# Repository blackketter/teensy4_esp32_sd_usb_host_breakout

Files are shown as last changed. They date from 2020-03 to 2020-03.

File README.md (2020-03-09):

# Teensy 4.0 ESP32 / USB Host / MicroSD Breakout Board

A jumbo breakout board with ESP32, USB-A host and microSD connectors to mate with the [Teensy 4 Header Breakout Board](https://github.com/blackketter/teensy4_header_breakout).

Additionally, the board includes a space for RTC Battery Holder and provides another Teensy reset/programming button (since it covers up the one on the Teensy).

It's designed to mount above or below the Teensy 4 and Header Breakout board on a relatively tall header.

Designed in KiCad.

### Notes:

- Status: Version 1.0 board ordered
- [OSHPark]() (https://oshpark.com/projects/xaSKCWHX)
- Download bom/ibom.html and view it with web browser to see bill of materials and placement information.

### Options

* Three jumpers on the back:
  * JP1 - Short to use Teensy 3.3v to power ESP32 (instead of onboard 3.3v regulator)
  * JP3 - Cut left side, bridge right side to disable D27 as USB Power Enable
  * JP2 - Cut to disable D29 as SD card detect

### Connectors
* J1 and J3 connect to the [Teensy 4 Header Breakout Board](https://github.com/blackketter/teensy4_header_breakout) pins via a header
* J5 is optional and provides access to the onboard 3.3v regulator
* J6 & J7 are optional and provide connection to the corresponding pins directly below on Teensy.  These connect the ESP32 SPI to the Teensy SPI port for high-speed goodness.  Should be compatible with the Adafruit Airlift firmware.
* J2 is a USB-A host connector
* J4 is a MicroSD push-pull connector

### Additional features
* Teensy programming button
* Socket for 12mm lithium backup batter for RTC
* RGB and White LEDs connected to ESP32 for additional status

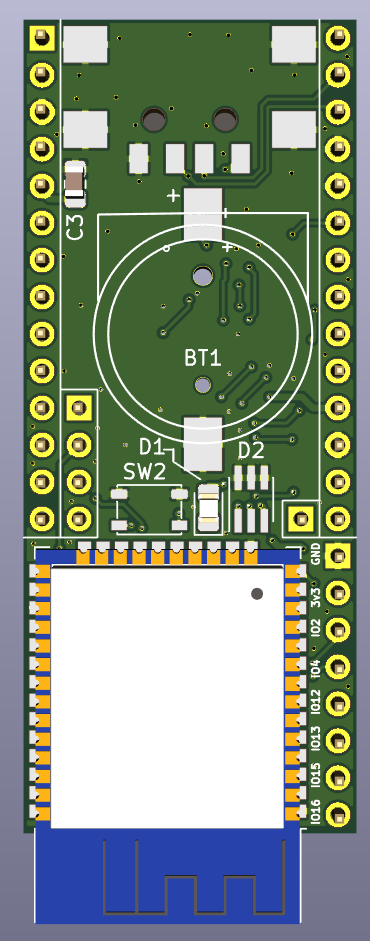
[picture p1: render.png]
breakout render

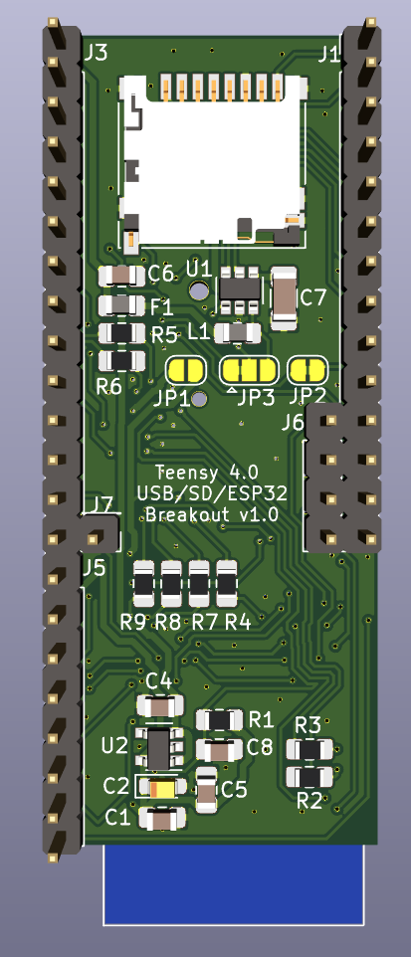
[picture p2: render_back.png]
breakout render_back

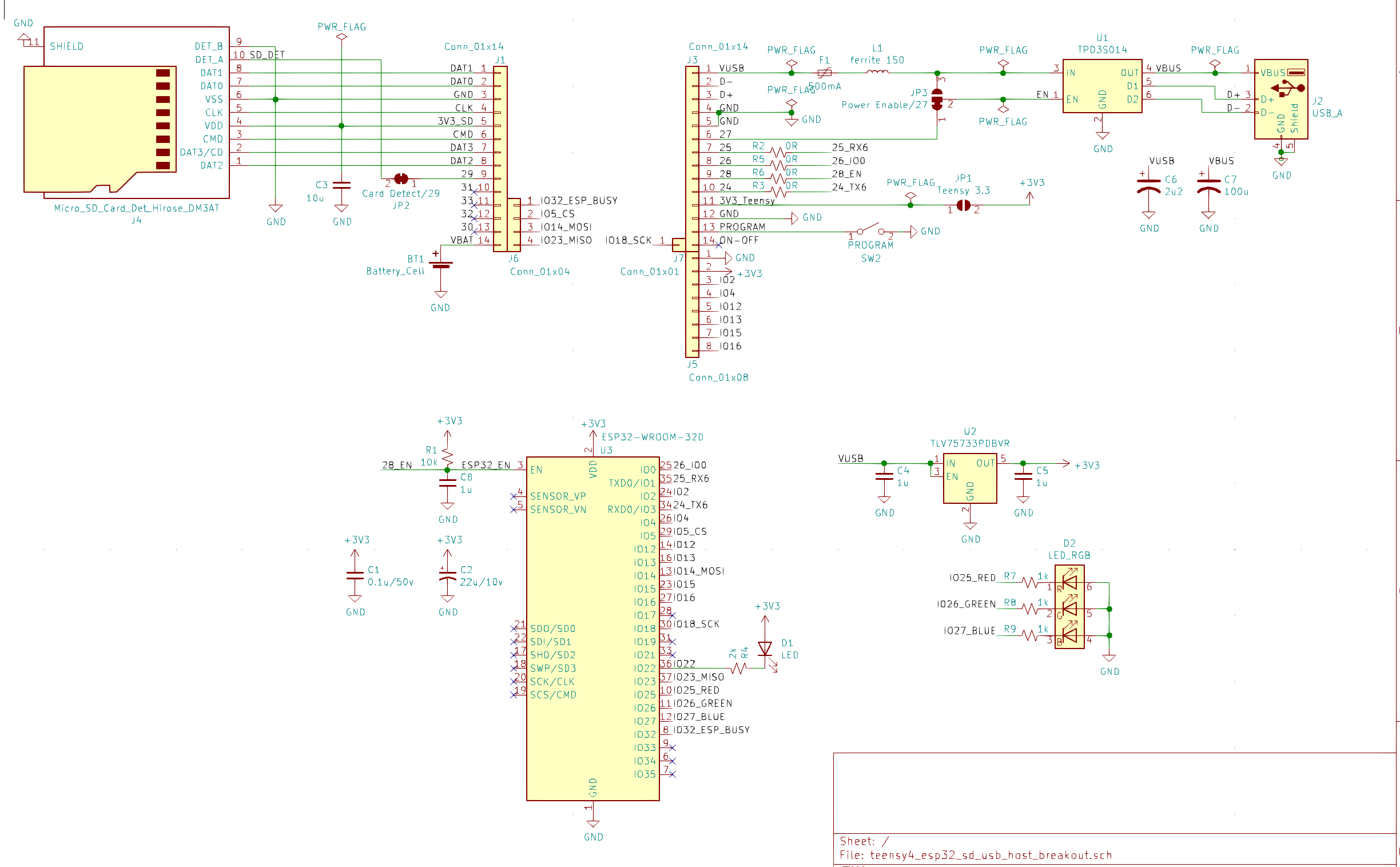
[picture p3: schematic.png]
schematic


**J1 - Left Side Pinout:**

1. Teensy D34 / SD DAT1
2. Teensy D35 / SD DAT0
3. GND
4. Teensy D36 / SD CLK
5. Teensy 3.3v
6. Teensy D37 / SD CMD
7. Teensy D38 / SD DAT3
8. Teensy D39 / SD DAT2
9. Teensy D29 / Card Detect
10. Teensy D31 (unused)
11. Teensy D33 (unused)
12. Teensy D32 (unused)
13. Teensy D30 (unused)
14. Teensy VBAT (battery backup)

**J3 - Right Side Pinout:**

1. Teensy VUSB
2. Teensy USB Host D-
3. Teensy USB Host D+
4. GND
5. GND
6. Teensy D27/USB Power EN
7. Teensy D25/ESP32 IO1 (Serial RX)
8. Teensy D26 / ESP32 IO0 (Boot Mode)
9. Teensy D28 / ESP32 EN (Reset)
10. Teensy D24 / ESP IO3 (Serial TX)
11. Teensy 3.3v
12. GND
13. Teensy Program
14. Teensy On/Off (unused)

**J5 - Optional additional pins**

15. GND
16. 3.3v from regulator on breakout board
17. ESP32 IO2
18. ESP32 IO4
19. ESP32 IO12
20. ESP32 IO13
21. ESP32 IO15
22. ESP32 IO16

**J6 - SPI between ESP32 and Teensy**

1. Teensy D9 / ESP32 IO32 (Busy)
2. Teensy D10 / ESP32 IO5 (CS)
3. Teensy D11 / ESP32 IO14 (MOSI)
4. Teensy D12 / ESP32 IO23 (MISO)

**J7 - SPI between ESP32 and Teensy (cont.)**

1. Teensy D13 / ESP32 IO18 (SCK)

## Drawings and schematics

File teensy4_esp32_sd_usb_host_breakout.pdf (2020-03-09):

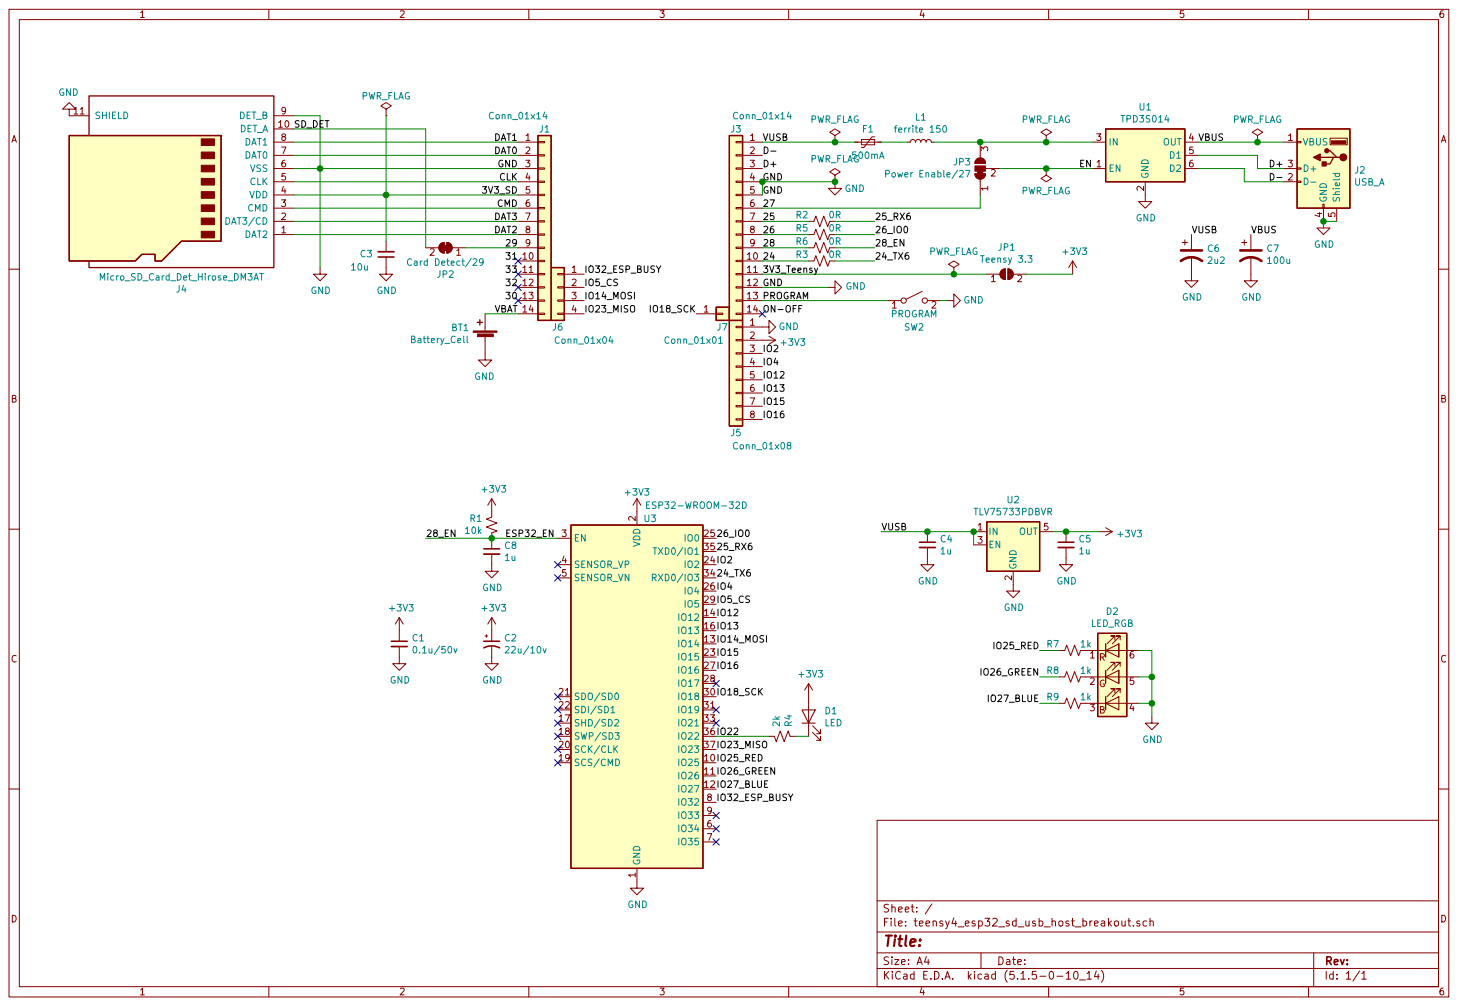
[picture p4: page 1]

CLK 4
3V3_SD 5

2 SCK/CLK 20 SDO/SD0 21 SDI/SD1 22

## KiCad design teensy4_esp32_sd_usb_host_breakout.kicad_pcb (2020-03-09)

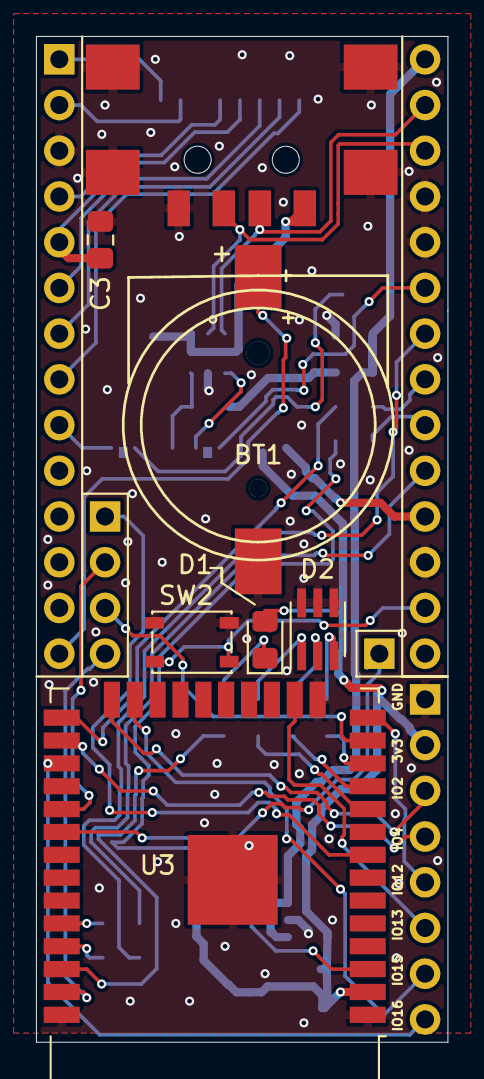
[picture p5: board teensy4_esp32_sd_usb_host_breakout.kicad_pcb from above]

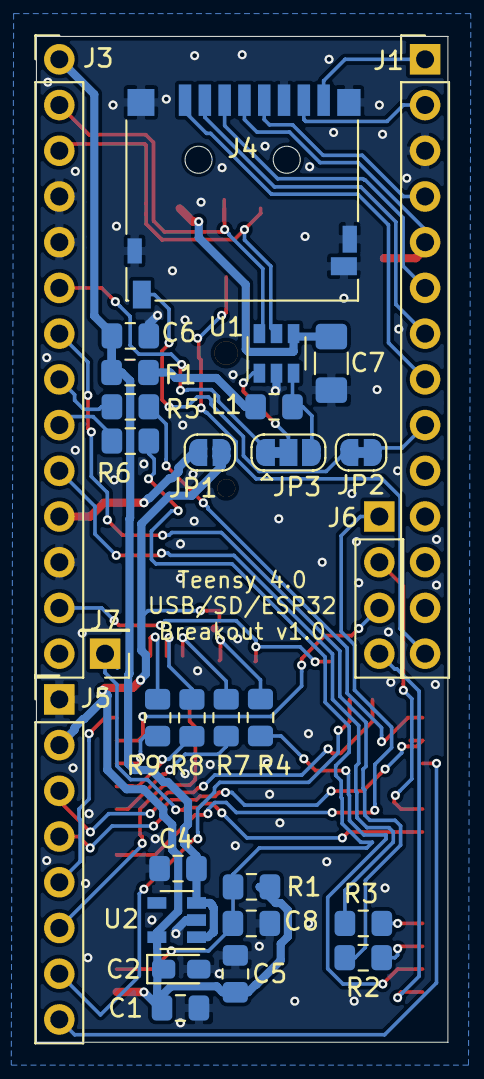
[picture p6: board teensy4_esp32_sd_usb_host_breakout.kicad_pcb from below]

Board: 2 copper layers, 22.9 x 55.9 mm, 36 parts (29 on the bottom side), 49 nets.

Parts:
BT1: Battery_Cell; BatteryHolder_MPD_BC501SM
C1: 0.1u/50v; C_0805_2012Metric_Pad1.15x1.40mm_HandSolder
C2: 22u/10v; CP_EIA-2012-12_Kemet-R_Pad1.30x1.05mm_HandSolder
C3: 10u; C_0805_2012Metric_Pad1.15x1.40mm_HandSolder
C4, C5, C8: 1u; C_0805_2012Metric_Pad1.15x1.40mm_HandSolder
C6: 2u2; C_0805_2012Metric_Pad1.15x1.40mm_HandSolder
C7: 100u; C_1206_3216Metric_Pad1.42x1.75mm_HandSolder
D1: LED; LED_0805_2012Metric_Pad1.15x1.40mm_HandSolder
D2: LED_RGB; LED_Avago_PLCC6_3x2.8mm
F1: 500mA; L_0805_2012Metric_Pad1.15x1.40mm_HandSolder
J1, J3: Conn_01x14; PinHeader_1x14_P2.54mm_Vertical
J2: USB_A; USB_A_Receptacle_SMD_Wuerth_629104190121_Narrow
J4: Micro_SD_Card_Det_Hirose_DM3AT; microSD_HC_Hirose_DM3D-SF
J5: Conn_01x08; PinHeader_1x08_P2.54mm_Vertical
J6: Conn_01x04; PinHeader_1x04_P2.54mm_Vertical
J7: Conn_01x01; PinHeader_1x01_P2.54mm_Vertical
JP1: Teensy 3.3; SolderJumper-2_P1.3mm_Open_RoundedPad1.0x1.5mm
JP2: Card Detect/29; SolderJumper-2_P1.3mm_Bridged_RoundedPad1.0x1.5mm
JP3: Power Enable/27; SolderJumper-3_P1.3mm_Bridged12_RoundedPad1.0x1.5mm
L1: ferrite 150; L_0805_2012Metric_Pad1.15x1.40mm_HandSolder
R1: 10k; R_0805_2012Metric_Pad1.15x1.40mm_HandSolder
R2, R3, R5, R6: 0R; R_0805_2012Metric_Pad1.15x1.40mm_HandSolder
R4: 2k; R_0805_2012Metric_Pad1.15x1.40mm_HandSolder
R7, R8, R9: 1k; R_0805_2012Metric_Pad1.15x1.40mm_HandSolder
SW2: PROGRAM; SW_SPST_PTS810
U1: TPD3S014; SOT-23-6
U2: TLV75733PDBVR; SOT-23-5
U3: ESP32-WROOM-32D; ESP32-WROOM-32

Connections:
+3V3: C1.1, C2.1, C5.1, D1.2, J5.2, JP1.2, R1.2, U2.5, U3.2
/3V3_SD: C3.2, J1.5, J4.4
/3V3_Teensy: J3.11, JP1.1
/24: J3.10, R3.2
/24_TX6: R3.1, U3.34
/25: J3.7, R2.2
/25_RX6: R2.1, U3.35
/26: J3.8, R5.2
/26_IO0: R5.1, U3.25
/27: J3.6, JP3.1
/28: J3.9, R6.2
/28_EN: C8.1, R1.1, R6.1, U3.3
/29: J1.9, JP2.1
/CLK: J1.4, J4.5
/CMD: J1.6, J4.3
/D+: J2.3, J3.3, U1.5
/D-: J2.2, J3.2, U1.6
/DAT0: J1.2, J4.7
/DAT1: J1.1, J4.8
/DAT2: J1.8, J4.1
/DAT3: J1.7, J4.2
/EN: JP3.2, U1.1
/IO2: J5.3, U3.24
/IO4: J5.4, U3.26
/IO5_CS: J6.2, U3.29
/IO12: J5.5, U3.14
/IO13: J5.6, U3.16
/IO14_MOSI: J6.3, U3.13
/IO15: J5.7, U3.23
/IO16: J5.8, U3.27
/IO18_SCK: J7.1, U3.30
/IO22: R4.1, U3.36
/IO23_MISO: J6.4, U3.37
/IO25_RED: R7.2, U3.10
/IO26_GREEN: R8.2, U3.11
/IO27_BLUE: R9.2, U3.12
/IO32_ESP_BUSY: J6.1, U3.8
/PROGRAM: J3.13, SW2.1
/SD_DET: J4.10, JP2.2
/VBAT: BT1.1, J1.14
/VBUS: C7.1, J2.1, U1.4
/VUSB: C4.1, C6.1, F1.2, J3.1, U2.1, U2.3
GND: BT1.2, C1.2, C2.2, C3.1, C4.2, C5.2, C6.2, C7.2, C8.2, D2.4, D2.5, D2.6, J1.3, J2.4, J2.5, J3.4, J3.5, J3.12, J4.6, J4.9, J4.11, J5.1, SW2.2, U1.2, U2.2, U3.1, U3.15, U3.38, U3.39
unnamed: D1.1, R4.2
unnamed: D2.1, R7.1
unnamed: D2.2, R8.1
unnamed: D2.3, R9.1
unnamed: F1.1, L1.1
unnamed: JP3.3, L1.2, U1.3

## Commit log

2020-03-08 first draft
    [teensy4_esp32_sd_usb_host_breakout.kicad_pcb, teensy4_esp32_sd_usb_host_breakout.sch]
2020-03-08 Second draft
    [teensy4_esp32_sd_usb_host_breakout.kicad_pcb]
2020-03-08 More details
    [teensy4_esp32_sd_usb_host_breakout.sch]
2020-03-08 Update readme, fix via sizes
    [teensy4_esp32_sd_usb_host_breakout.kicad_pcb, teensy4_esp32_sd_usb_host_breakout.sch]
2020-03-09 Version 1.0 Ordered
    [teensy4_esp32_sd_usb_host_breakout.kicad_pcb, teensy4_esp32_sd_usb_host_breakout.sch]
